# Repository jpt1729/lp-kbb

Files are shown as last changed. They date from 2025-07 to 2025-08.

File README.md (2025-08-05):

# Low-profile Keyboard

This is a low profile 65% keyboard with a rotary encoder (for volume + mute/unmute). This project uses Gateron's ks33 switches and their respective hotswap sockets. This is all on top of a skeletal 3d printed case. (also texas themed)

I made this project because 1 I just want a custom keyboard and 2 the keyboard I want kinda doesn't exist. I don't haven't really seen these keyboard with the skeletal cases or chamfered edges so I kinda wanted to make it + its texas themed :).

# Photos






# BOM
| Item | Quantity Used | Quantity Purchased | Designator | Part Number / Description | Link | Cost |
|---|---|---|---|---|---|---|
| Gateron Grey Heron LP Switches | 70 | 2 (35-pack) | SW1–SW70 | Gateron Low‑Profile Grey Heron | [Gateron](https://www.gateron.com/products/gateron-low-profile-grey-heron-switch?VariantsId=10866) | $30.10 |
| Gateron Sky Plate-Mounted Stabilizer | 1 | 1 | STAB1 | Gateron Low‑Profile Stabilizer | [Gateron](https://www.gateron.com/products/gateron-low-profile-sky-plate-mounted-stabilizer) | $10.00 |
| Gateron Hot‑Swap PCB Socket | 1 | 1 | S1 | LP Hotswap Socket | [Gateron](https://www.gateron.com/products/gateron-low-profile-switch-hot-swap-pcb-socket?VariantsId=10233) | $7.00 |
| Low profile keycaps | 1 | 1 | | Keycaps | [kbdcraft](https://kbdcraft.store/products/keycap-lp) | $20.35 |
| EC11 | 1 | 1 | EC11 | EC11 Encoder |  | *Owned* |
| 1N4148 Diodes | 1 | 1 | D | Keyboard Diodes | [AliExpress](https://www.aliexpress.us/item/2255799955957794.html) | $1.48 |
| Heatset inserts| 1 | 1 |  | | [AliExpress](https://www.aliexpress.us/item/3256807534424119.html) | $2.71 |
| Orpheus Pico | 1 | 1 | U1 | RP2040 Custom Module |  | *Owned* |
| EC11 Encoder | 1 | 1 | ENC2 | EC11 (Spare) |  | *Owned* |
| Headers | 1 | 1 | | 2.54mm Male/Female Headers | [AliExpress](https://www.aliexpress.us/item/2255800687544049.html) | $1.99 |
| PCB (w/o discount) + shipping | 1 | 5 |  | JLCPCB |  | $30.76 |
| Case | 1 | 1 |  | 3d printed case |  | |
| Shipping Gateron (+ Gateron service fee) |  |  |  | Shipping from Gateron |  | $11.23 |
| Shipping AliExpress |  |  |  | Shipping from AliExpress |  | $3.00 |
| **Total** |  |  |  | | | **$118.62** |

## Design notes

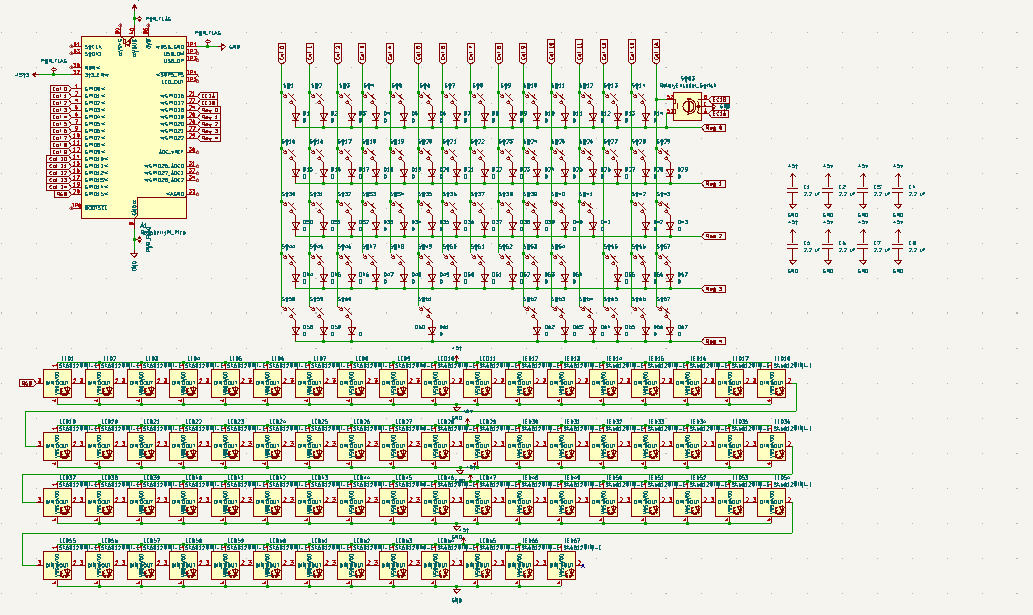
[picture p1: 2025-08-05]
photos/schematic.png

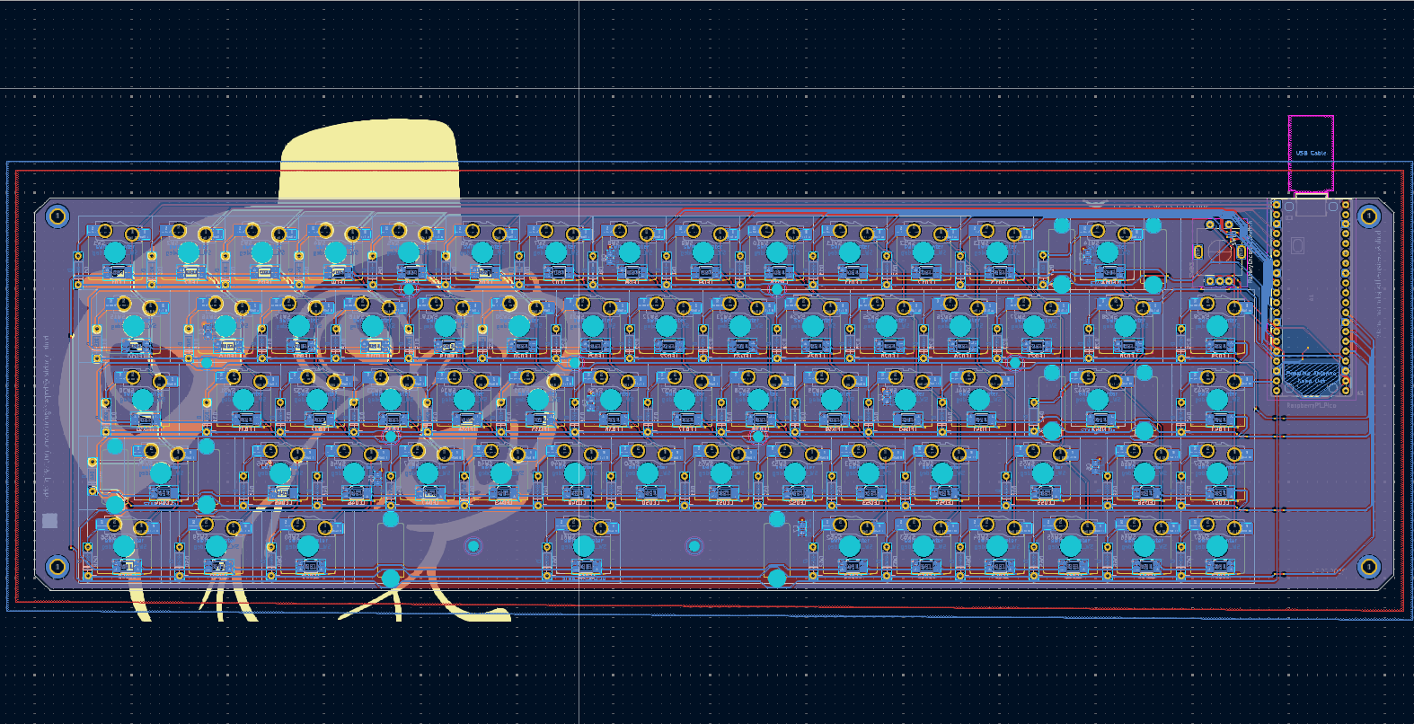
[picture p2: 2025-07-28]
photos/Screenshot 2025-07-27 214924.png

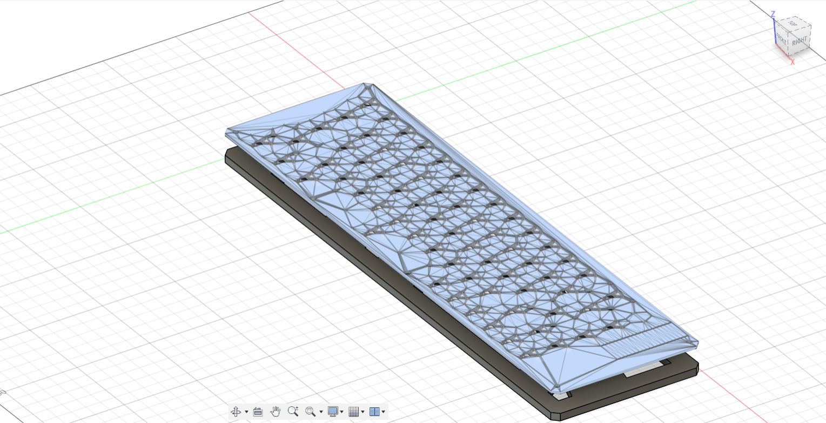
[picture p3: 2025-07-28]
photos/Screenshot 2025-07-24 174013.png

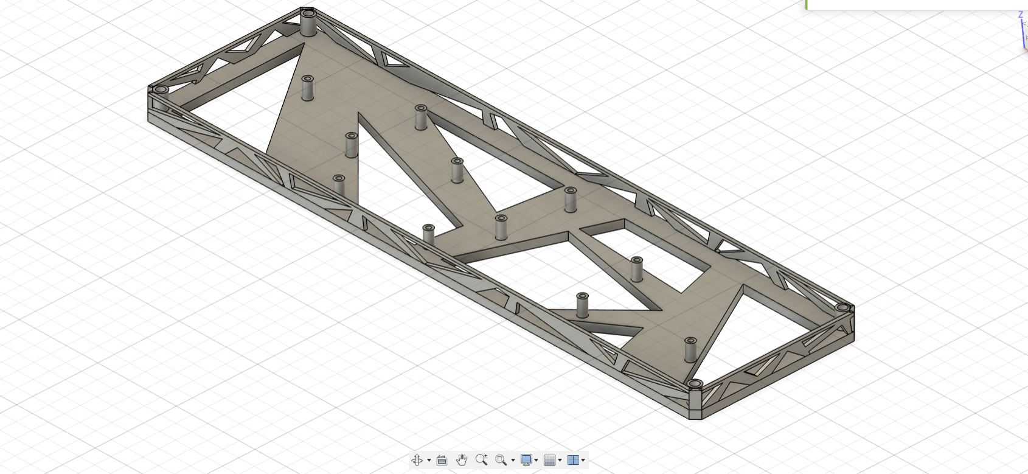
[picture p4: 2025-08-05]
photos/case-solo-8-5-2025.png

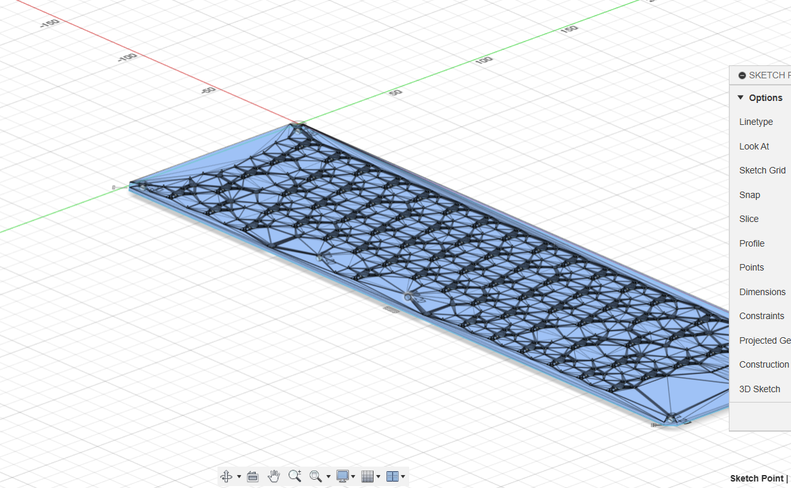
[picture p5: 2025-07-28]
photos/Screenshot 2025-07-24 172412.png

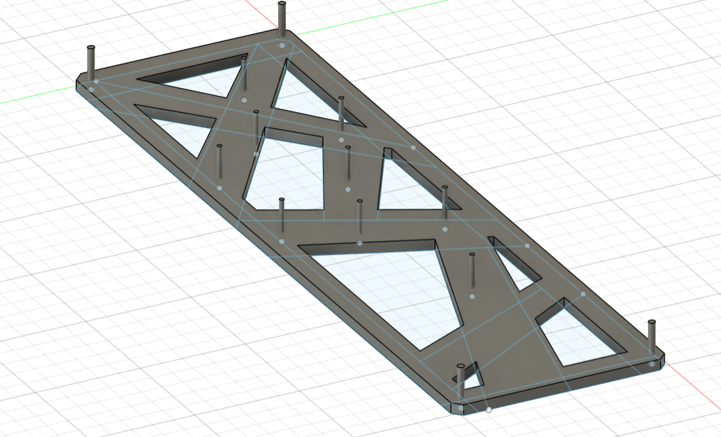
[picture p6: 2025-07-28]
photos/Screenshot 2025-07-24 174416.png

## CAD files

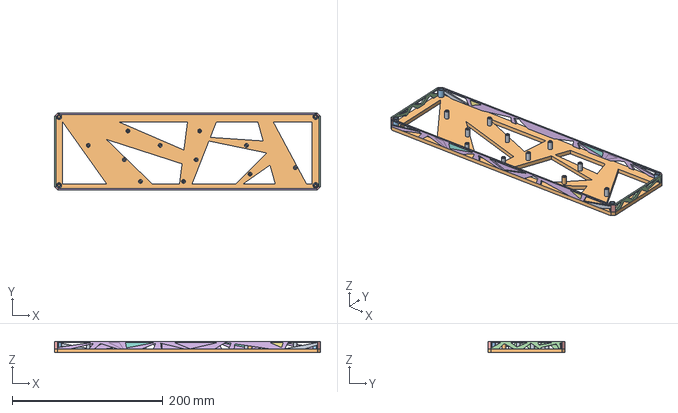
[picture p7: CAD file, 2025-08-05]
case/case.step
352.4 x 101.8 x 15.0 mm

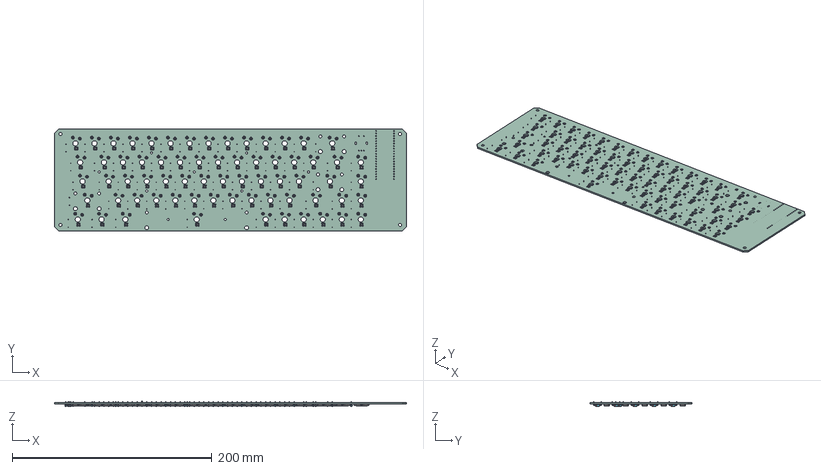
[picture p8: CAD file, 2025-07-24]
PCB/modern-keyboard.step
352.4 x 101.8 x 5.01 mm
D_DO-35_SOD27_P7.62mm_Horizontal x 67
HS_KS-2P02B01-02_KS33 x 67
LED_SK6812MINI-E x 67
modern-keyboard_PCB

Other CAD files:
PCB/lp-kbb-pcb.f3d

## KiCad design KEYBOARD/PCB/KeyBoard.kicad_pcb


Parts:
A1: RaspberryPi_Pico; RaspberryPi_Pico_Common_Unspecified
D1, D2, D3, D4, D5, D6, D7, D8, D9, D10, D11, D12, D13, D14, D15, D16, D17, D18, D19, D20, D21, D22, D23, D24, D25, D26, D27, D28, D29, D30, D31, D32, D33, D34, D35, D36, D37, D38, D39, D40, D41, D42, D43, D44, D45, D46, D47, D48, D49, D50, D51, D52, D53, D54, D55, D56, D57, D58, D59, D60, D61: 1N4148; D_DO-35_SOD27_P7.62mm_Horizontal
S1: MX_stab; STAB_MX_2u
S2, S3: MX_stab; STAB_MX_2.25u
S4: MX_stab; STAB_MX_2.75u
S5: MX_stab; STAB_MX_6.25u
SW1, SW2, SW3, SW4, SW5, SW6, SW7, SW8, SW9, SW10, SW11, SW12, SW13, SW16, SW17, SW18, SW19, SW20, SW21, SW22, SW23, SW24, SW25, SW26, SW27, SW30, SW31, SW32, SW33, SW34, SW35, SW36, SW37, SW38, SW39, SW40, SW51, SW52, SW53, SW54, SW55, SW56, SW57, SW58, SW59, SW60: SW_Push; SW_Cherry_MX_1.00u_PCB
SW14: SW_Push; SW_Cherry_MX_2.00u_PCB
SW15: SW_Push; SW_Cherry_MX_1.50u_PCB
SW28: SW_Push; SW_Cherry_MX_1.50u_Plate
SW29: SW_Push; SW_Cherry_MX_1.75u_PCB
SW41, SW50: SW_Push; SW_Cherry_MX_2.25u_PCB
SW42, SW43, SW44, SW46, SW48, SW49: SW_Push; SW_Cherry_MX_1.25u_PCB
SW45: SW_Push; SW_Cherry_MX_6.25u_PCB
SW47: SW_Push; SW_Cherry_MX_1.25u_Plate
SW61: SW_Push; SW_Cherry_MX_2.75u_PCB
SW62, SW63: RotaryEncoder_Switch_MP; RotaryEncoder_Alps_EC11E-Switch_Vertical_H20mm

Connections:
A1: A1.27 (GPIO21), SW62.A
A2: A1.32 (GPIO27_ADC1), SW63.A
B1: A1.29 (GPIO22), SW62.B
B2: A1.34 (GPIO28_ADC2), SW63.B
C0: A1.10 (GPIO7), SW1.1, SW15.1, SW29.1, SW42.1, SW50.1
C1: A1.11 (GPIO8), SW2.1, SW16.1, SW30.1, SW43.1, SW51.1
C2: A1.12 (GPIO9), SW3.1, SW17.1, SW31.1, SW44.1, SW52.1
C3: A1.14 (GPIO10), SW4.1, SW18.1, SW32.1, SW53.1
C4: A1.15 (GPIO11), SW5.1, SW19.1, SW33.1, SW54.1
C5: A1.16 (GPIO12), SW6.1, SW20.1, SW34.1, SW45.1, SW55.1
C6: A1.17 (GPIO13), SW7.1, SW21.1, SW35.1, SW56.1
C7: A1.19 (GPIO14), SW8.1, SW22.1, SW36.1, SW57.1
C8: A1.20 (GPIO15), SW9.1, SW23.1, SW37.1, SW46.1, SW58.1
C9: A1.21 (GPIO16), SW10.1, SW24.1, SW38.1, SW47.1, SW59.1
C10: A1.22 (GPIO17), SW11.1, SW25.1, SW39.1, SW48.1, SW60.1
C11: A1.24 (GPIO18), SW12.1, SW26.1, SW40.1, SW49.1, SW61.1
C12: A1.25 (GPIO19), SW13.1, SW27.1, SW41.1
C13: A1.26 (GPIO20), SW14.1, SW28.1
GND: A1.33 (AGND), SW62.C, SW62.S2, SW63.C, SW63.S2
unnamed: A1.3 (GND), A1.8 (GND), A1.13 (GND), A1.18 (GND), A1.23 (GND), A1.28 (GND), A1.38 (GND)
unnamed: D1.2 (A), SW1.2
unnamed: D2.2 (A), SW2.2
unnamed: D3.2 (A), SW3.2
unnamed: D4.2 (A), SW4.2
unnamed: D5.2 (A), SW5.2
unnamed: D6.2 (A), SW6.2
unnamed: D7.2 (A), SW7.2
unnamed: D8.2 (A), SW8.2
unnamed: D9.2 (A), SW9.2
unnamed: D10.2 (A), SW10.2
unnamed: D11.2 (A), SW11.2
unnamed: D12.2 (A), SW12.2
unnamed: D13.2 (A), SW13.2
unnamed: D14.2 (A), SW14.2
unnamed: D15.2 (A), SW15.2
unnamed: D16.2 (A), SW16.2
unnamed: D17.2 (A), SW17.2
unnamed: D18.2 (A), SW18.2
unnamed: D19.2 (A), SW19.2
unnamed: D20.2 (A), SW20.2
unnamed: D21.2 (A), SW21.2
unnamed: D22.2 (A), SW22.2
unnamed: D23.2 (A), SW23.2
unnamed: D24.2 (A), SW24.2
unnamed: D25.2 (A), SW25.2
unnamed: D26.2 (A), SW26.2
unnamed: D27.2 (A), SW27.2
unnamed: D28.2 (A), SW28.2
unnamed: D29.2 (A), SW29.2
unnamed: D30.2 (A), SW30.2
unnamed: D31.2 (A), SW31.2
unnamed: D32.2 (A), SW32.2
unnamed: D33.2 (A), SW33.2
unnamed: D34.2 (A), SW34.2
unnamed: D35.2 (A), SW35.2
unnamed: D36.2 (A), SW36.2
unnamed: D37.2 (A), SW37.2
unnamed: D38.2 (A), SW38.2
unnamed: D39.2 (A), SW39.2
unnamed: D40.2 (A), SW40.2
unnamed: D41.2 (A), SW41.2
unnamed: D42.2 (A), SW42.2
unnamed: D43.2 (A), SW43.2
unnamed: D44.2 (A), SW44.2
unnamed: D45.2 (A), SW45.2
unnamed: D46.2 (A), SW46.2
unnamed: D47.2 (A), SW47.2
unnamed: D48.2 (A), SW48.2
unnamed: D49.2 (A), SW49.2
unnamed: D50.2 (A), SW50.2
unnamed: D51.2 (A), SW51.2
unnamed: D52.2 (A), SW52.2
unnamed: D53.2 (A), SW53.2
unnamed: D54.2 (A), SW54.2
unnamed: D55.2 (A), SW55.2
unnamed: D56.2 (A), SW56.2
unnamed: D57.2 (A), SW57.2
unnamed: D58.2 (A), SW58.2
unnamed: D59.2 (A), SW59.2
unnamed: D60.2 (A), SW60.2
unnamed: D61.2 (A), SW61.2
R0: A1.4 (GPIO2), D1.1 (K), D2.1 (K), D3.1 (K), D4.1 (K), D5.1 (K), D6.1 (K), D7.1 (K), D8.1 (K), D9.1 (K), D10.1 (K), D11.1 (K), D12.1 (K), D13.1 (K), D14.1 (K)
R1: A1.5 (GPIO3), D15.1 (K), D16.1 (K), D17.1 (K), D18.1 (K), D19.1 (K), D20.1 (K), D21.1 (K), D22.1 (K), D23.1 (K), D24.1 (K), D25.1 (K), D26.1 (K), D27.1 (K), D28.1 (K)
R2: A1.6 (GPIO4), D29.1 (K), D30.1 (K), D31.1 (K), D32.1 (K), D33.1 (K), D34.1 (K), D35.1 (K), D36.1 (K), D37.1 (K), D38.1 (K), D39.1 (K), D40.1 (K), D41.1 (K)
R3: A1.7 (GPIO5), D50.1 (K), D51.1 (K), D52.1 (K), D53.1 (K), D54.1 (K), D55.1 (K), D56.1 (K), D57.1 (K), D58.1 (K), D59.1 (K), D60.1 (K), D61.1 (K)
R4: A1.9 (GPIO6), D42.1 (K), D43.1 (K), D44.1 (K), D45.1 (K), D46.1 (K), D47.1 (K), D48.1 (K), D49.1 (K)
S1: A1.31 (GPIO26_ADC0), SW62.S1
S2: A1.2 (GPIO1), SW63.S1



Board: 2 copper layers, 321.0 x 101.0 mm, 130 parts (61 on the bottom side), 88 nets.

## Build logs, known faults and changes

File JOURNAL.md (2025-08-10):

---
title: "Highway Keyboard"
author: "jpt1729"
description: "A low-profile 60% keyboard"
created_at: "2025-07-18"
---

## Total hours: 23 hrs

For transparency sake, I took some of the screen shots after the date because I realized it was a requirement so some stuff might get mixed up!

# 7/19/2025

Been working on this for a little bit working on the schematic. One thing that happened the last time I designed this is I would delete random switches which would mess up the numbering so I am not doing that now!!!. 

I have designed out the PCB and the Schematic (only the keys so far) and have decided to go with a pico. 

Got pretty far but realized I was building an inverted keyboard which is exactly what I don't want. Fixed it and placed the LEDs




**Hours spent: 4 hrs**

# 7/20/2025

I've been working some more on the project. I made a couple of mistakes, but now they are fixed. The LEDs in the PCB are wired and so are the diodes. Working on connecting everything so that I can start adding the smaller bits and pieces to the PCB (art, screw holes, rounded corners, etc.). So far its looking really good. The LEDs are gunna be hard to solder but I should be good.

I got the keyboard basically all wired up I just need the columns and to wire up the ec11 and we gooooooddddd.

**Hours spent: 6 hrs**



# 7/21/2025

Ok so now we are almost done! So I finished the PCB I decided to go with chamfered edges instead of rounded corners cause I feel like it will look cooler with the case. I want a case with a skeletal design.

Today, I finished wiring up everything putting the screws and all the stabalizers.

**Hours spent: 1.5 hrs**



# 7/22/2025

Today I want to finish the project which means case design + firmware + art on pcb.

Starting with the Art on the PCB.

I finished the case I looks really nice and has the skeletal look I wanted

**Hours spent: 2.5 hrs**




# 7/25/2025

Writing the QMK firmware!

**Hours spent: 2 hrs**

# 7/27/2025

Getting everything written out to be approved. BOM stuff and finding parts. taking screen shots. making sure everything is perfect!!!

**Hours spent: 2 hrs**

## Revisions!

# 8/4/2025

Redesigned the case. Had to do it from scratch and add some "complexity" which for me was including walls that are skeletal (I don't want a top cause why did I add pcb art js to cover it??)



**Hours spent: 4 hrs**

# 8/5/2025

Quick fixes to BOM README.md journal and taking photos and stuff

**Hours spent: 1 hr**

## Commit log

2025-07-19 initial PCBs
    [modern-keyboard.kicad_pcb, modern-keyboard.kicad_sch]
2025-07-19 correct side correct orientation keyboard + leds
    [modern-keyboard.kicad_pcb, modern-keyboard.kicad_sch]
